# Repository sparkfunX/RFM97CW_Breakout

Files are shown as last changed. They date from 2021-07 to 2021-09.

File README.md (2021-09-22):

SparkFun RFM97C Mini Shield LoRa - 100mW
========================================

SparkFun RFM97C Mini Shield LoRa - 100mW (https://www.sparkfun.com/products/18574)

[*SparkFun RFM97C Mini Shield LoRa - 100mW (SPX-18574)*](https://www.sparkfun.com/products/18574)

The RFM97C is a great little module that incorporates the [SX1276 LoRa transceiver](https://www.semtech.com/products/wireless-rf/lora-core/sx1276) from Semtech. LoRa is best for long range communication (hundreds of feet), low power, and low data rates (~500bps). This 'Mini Shield' is designed to be attached to the top or bottom of any of our Thing Plus boards. Pictured is the [ESP32 Thing Plus](https://www.sparkfun.com/products/18018). We include a PTH soldering point for a low cost wire antenna (~3" for 915MHz) along side a stress relief hole. For folks that need a bit more oomph, there is a U.FL connector available for larger, external RP-SMA LoRa antennas.

Our example sketches make quick work of the initial setup, and the RadioLib Arduino Library makes advanced configuration and [protocols](https://github.com/jgromes/RadioLib/wiki/Default-configuration#protocols) (AX.25, Hellschreiber, Morse, RTTY, and SSTV) a cinch too!

Repository Contents
-------------------

* **/Documents** - Datasheets and mechanical drawings
* **/Firmware** - Example sketch(es)
* **/Hardware** - All Eagle design files (.brd, .sch, .STL)

Product Versions
----------------

* [SPX-18574](https://www.sparkfun.com/products/18574)

License Information
-------------------

This product is _**open source**_! 

Please review the LICENSE.md file for license information. 

If you have any questions or concerns on licensing, please contact technical support on our [SparkFun forums](https://forum.sparkfun.com/viewforum.php?f=152).

Distributed as-is; no warranty is given.

- Your friends at SparkFun.

_<COLLABORATION CREDIT>_

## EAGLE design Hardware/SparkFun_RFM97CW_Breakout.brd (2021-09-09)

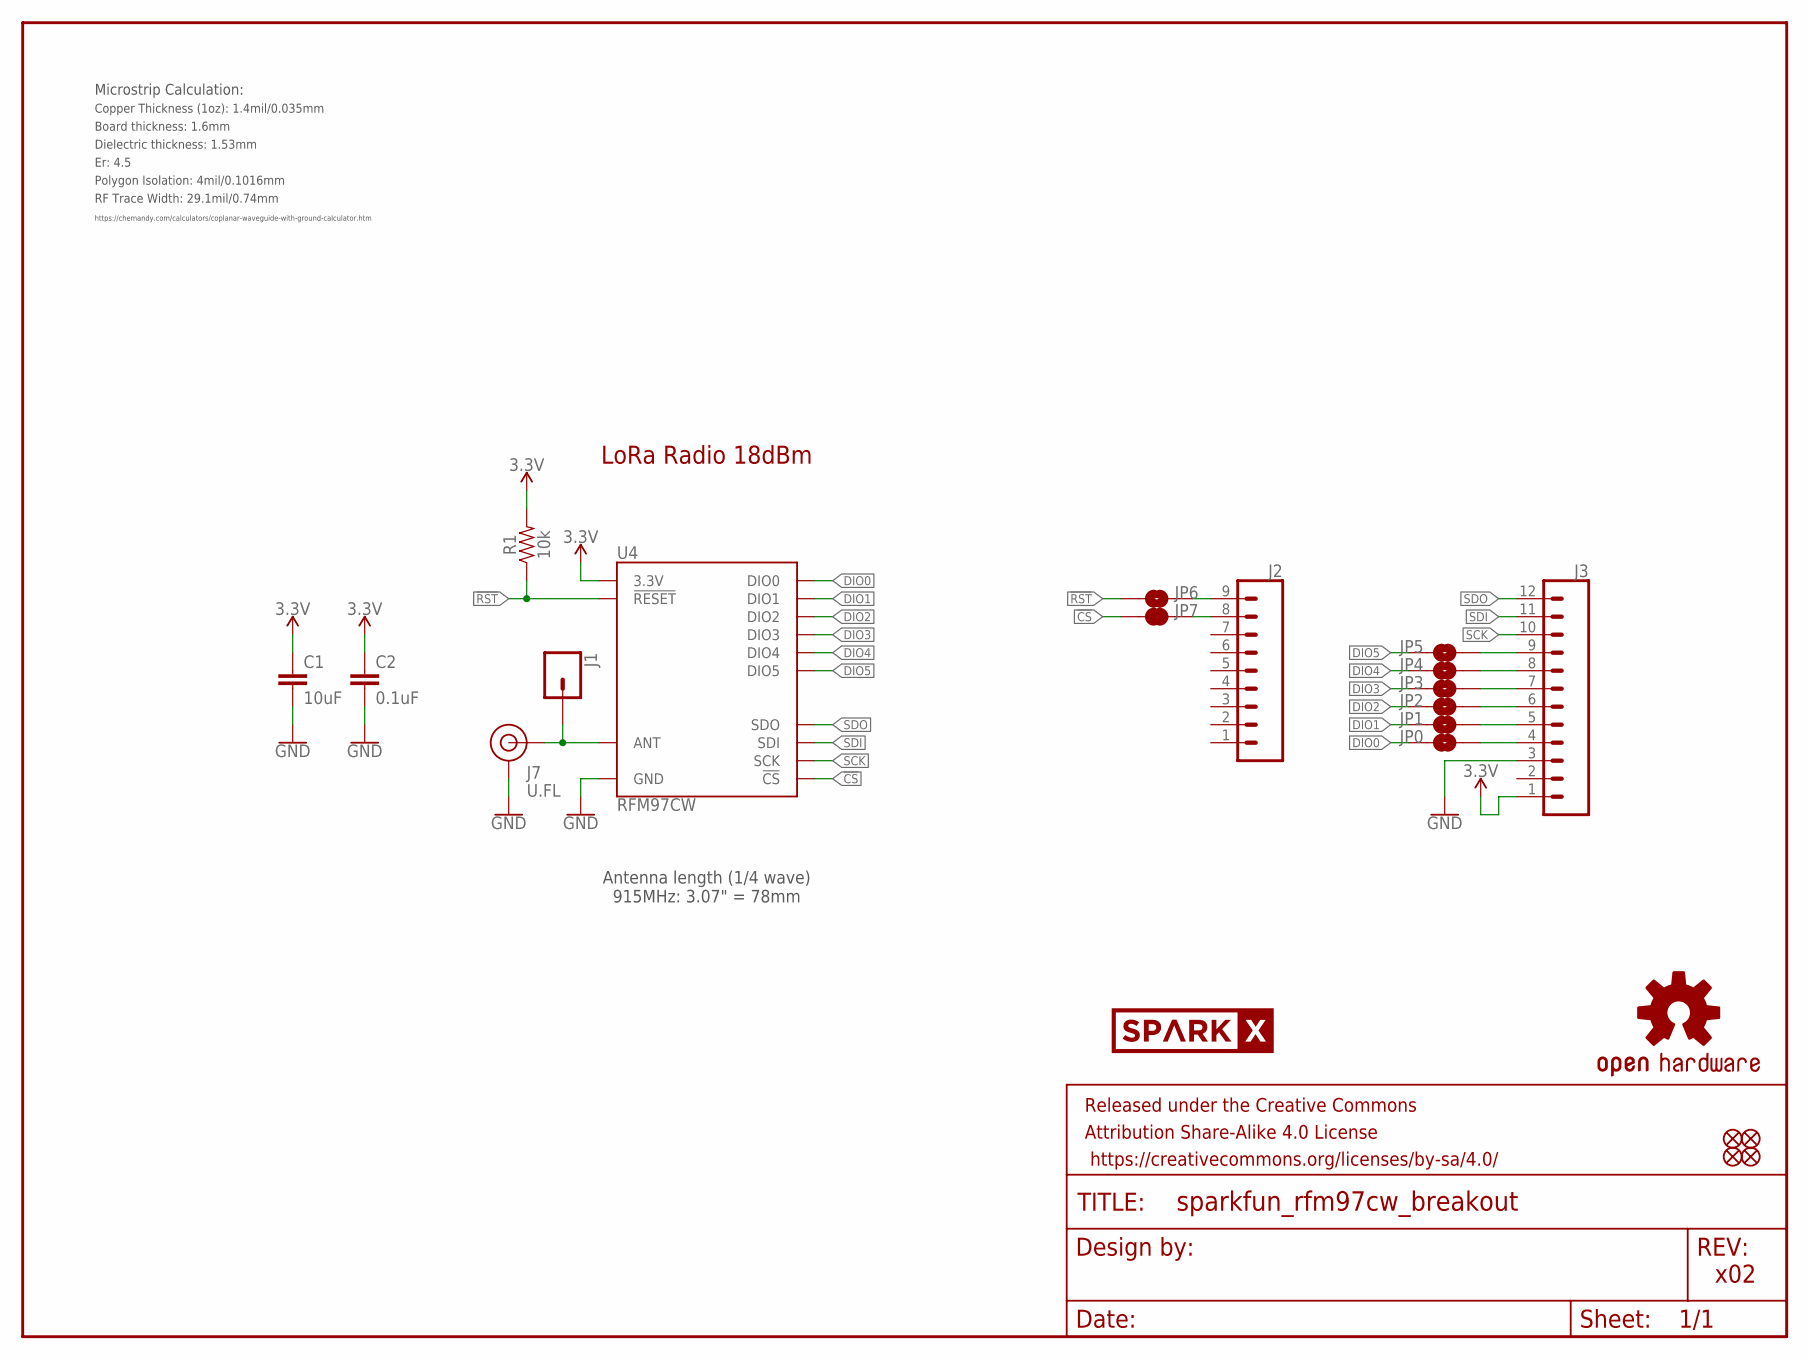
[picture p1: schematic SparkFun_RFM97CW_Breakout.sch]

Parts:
C1: 10uF; 0603
C2: 0.1uF; 0603
FID1, FID2, FID3, FID4: FIDUCIAL1X2; FIDUCIAL-1X2
FRAME1: FRAME-LETTER; CREATIVE_COMMONS
J1: CONN_01PTH_NO_SILK_YES_STOP; 1X01_NO_SILK
J2: CONN_09NO_SILK; 1X09_NO_SILK
J3: CONN_12NO_SILK; 1X12_NO_SILK
J7: U.FL
JP0, JP1, JP2, JP3, JP4, JP5, JP6: JUMPER-SMT_2_NO_NO-SILK; SMT-JUMPER_2_NO_NO-SILK
JP7: JUMPER-SMT_2_NC_TRACE_NO-SILK; SMT-JUMPER_2_NC_TRACE_NO-SILK
LOGO2: OSHW-LOGOS; OSHW-LOGO-S
R1: 10k; 0603
U4: RFM97CW; RFM97
U$22: SPARKX-LOGO5; SPARKX-LARGE

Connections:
3.3V: C1.1, C2.1, J3.1, R1.2, U4.3V3 (3.3V)
!CS!: JP7.1, U4.!CS!
!RST!: JP6.1, R1.1, U4.!RST (!RESET)
ANT: J1.1, J7.FEED (SIGNAL), U4.ANT
DIO0: JP0.1, U4.DIO0
DIO1: JP1.1, U4.DIO1
DIO2: JP2.1, U4.DIO2
DIO3: JP3.1, U4.DIO3
DIO4: JP4.1, U4.DIO4
DIO5: JP5.1, U4.DIO5
GND: C1.2, C2.2, J3.3, J7.1 (GND), J7.2 (GND), U4.GND, U4.GND@1 (GND), U4.GND@2 (GND)
unnamed: J3.6, JP2.2
unnamed: J2.9, JP6.2
unnamed: J2.8, JP7.2
unnamed: J3.5, JP1.2
unnamed: J3.4, JP0.2
unnamed: J3.7, JP3.2
unnamed: J3.8, JP4.2
unnamed: J3.9, JP5.2
SCK: J3.10, U4.SCK
SDI: J3.11, U4.SDI
SDO: J3.12, U4.SDO

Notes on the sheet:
x02
Antenna length (1/4 wave) 915MHz: 3.07" = 78mm
Board thickness: 1.6mm
Er: 4.5
Copper Thickness (1oz): 1.4mil/0.035mm
RF Trace Width: 29.1mil/0.74mm
Polygon Isolation: 4mil/0.1016mm
Dielectric thickness: 1.53mm
https://chemandy.com/calculators/coplanar-waveguide-with-ground-calculator.htm
Microstrip Calculation:
LoRa Radio 18dBm

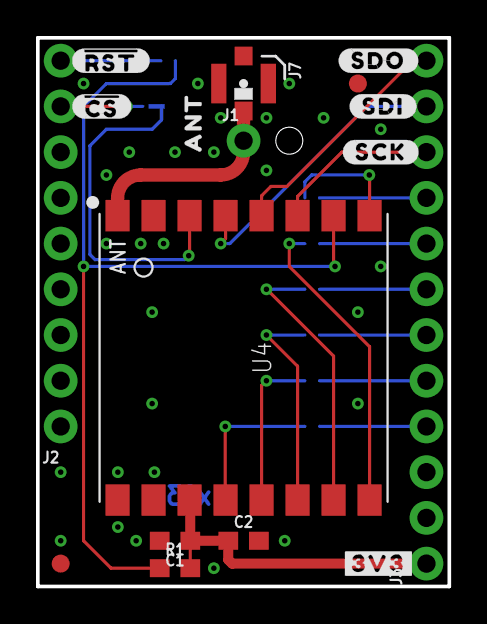
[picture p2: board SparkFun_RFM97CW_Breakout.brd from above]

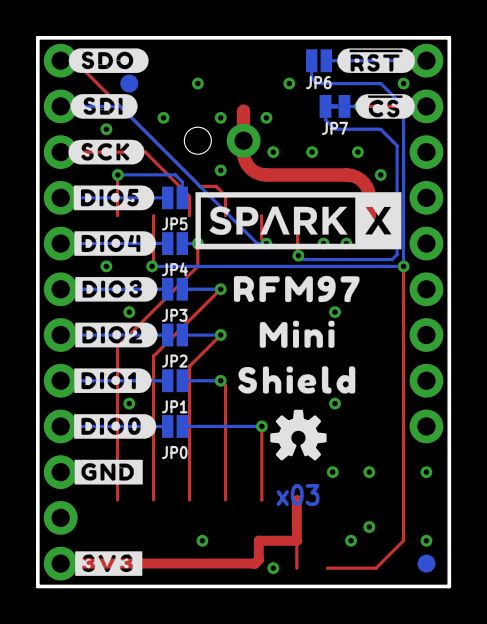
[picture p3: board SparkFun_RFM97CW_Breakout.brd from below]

Board: 2 copper layers, 22.9 x 30.5 mm, 46 parts (28 on the bottom side), 22 nets.

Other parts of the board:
U$1: ANT0
U$2, U$21: ##CS##2
U$3, U$7: #SDO#0
U$4, U$6: #SDI#1
U$5, U$12: #SCK#0
U$8, U$9: #3V3#0
U$10: #GND#1
U$11: MINI0
U$13, U$17: ##RST##0
U$19: RFM970
U$20: SHIELD2
U$23: #DIO0#0
U$24: #DIO1#0
U$25: #DIO2#0
U$26: #DIO3#0
U$27: #DIO4#0
U$28: #DIO5#0

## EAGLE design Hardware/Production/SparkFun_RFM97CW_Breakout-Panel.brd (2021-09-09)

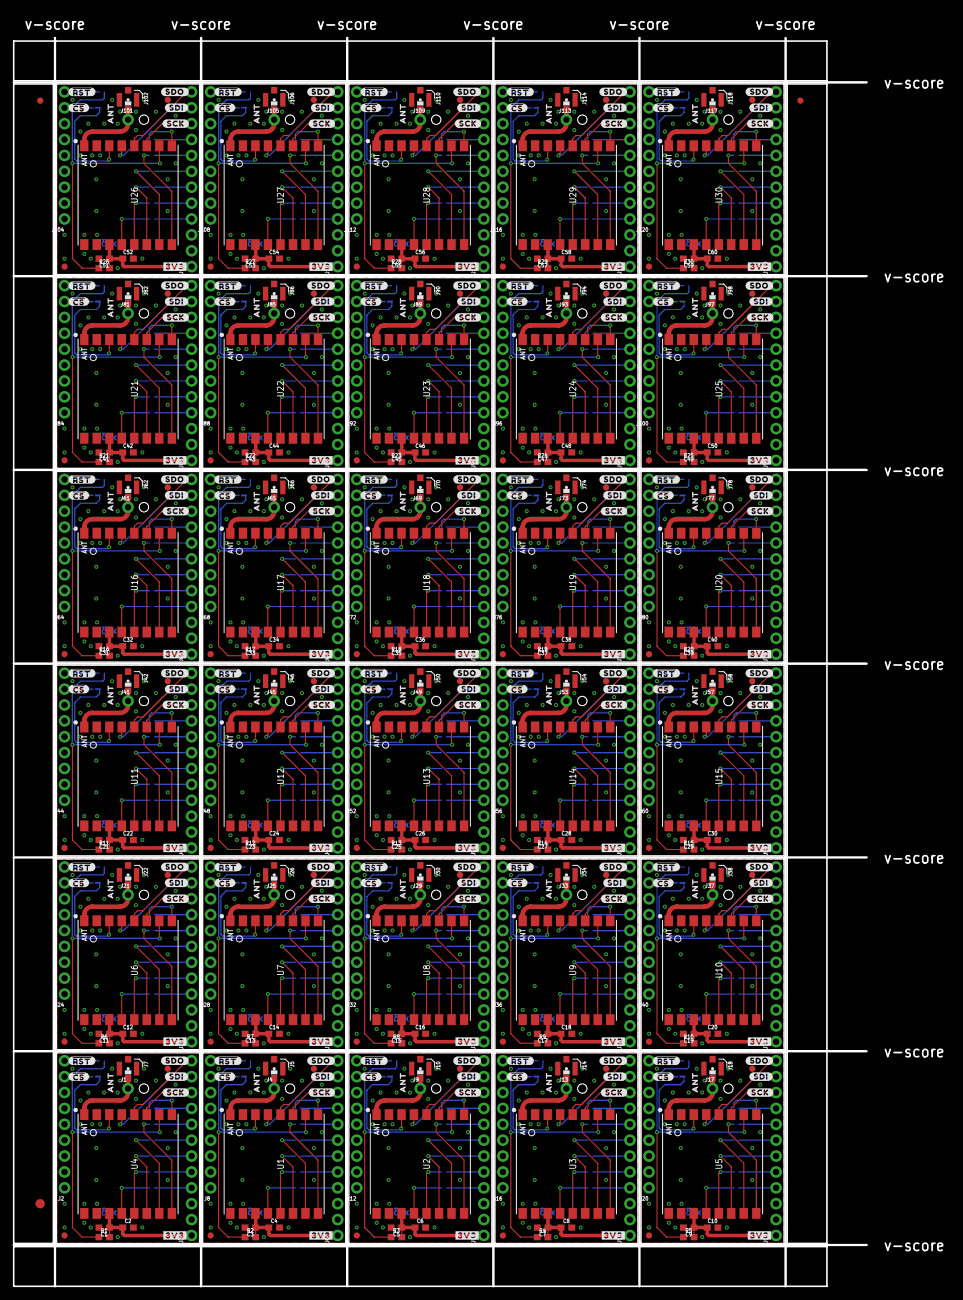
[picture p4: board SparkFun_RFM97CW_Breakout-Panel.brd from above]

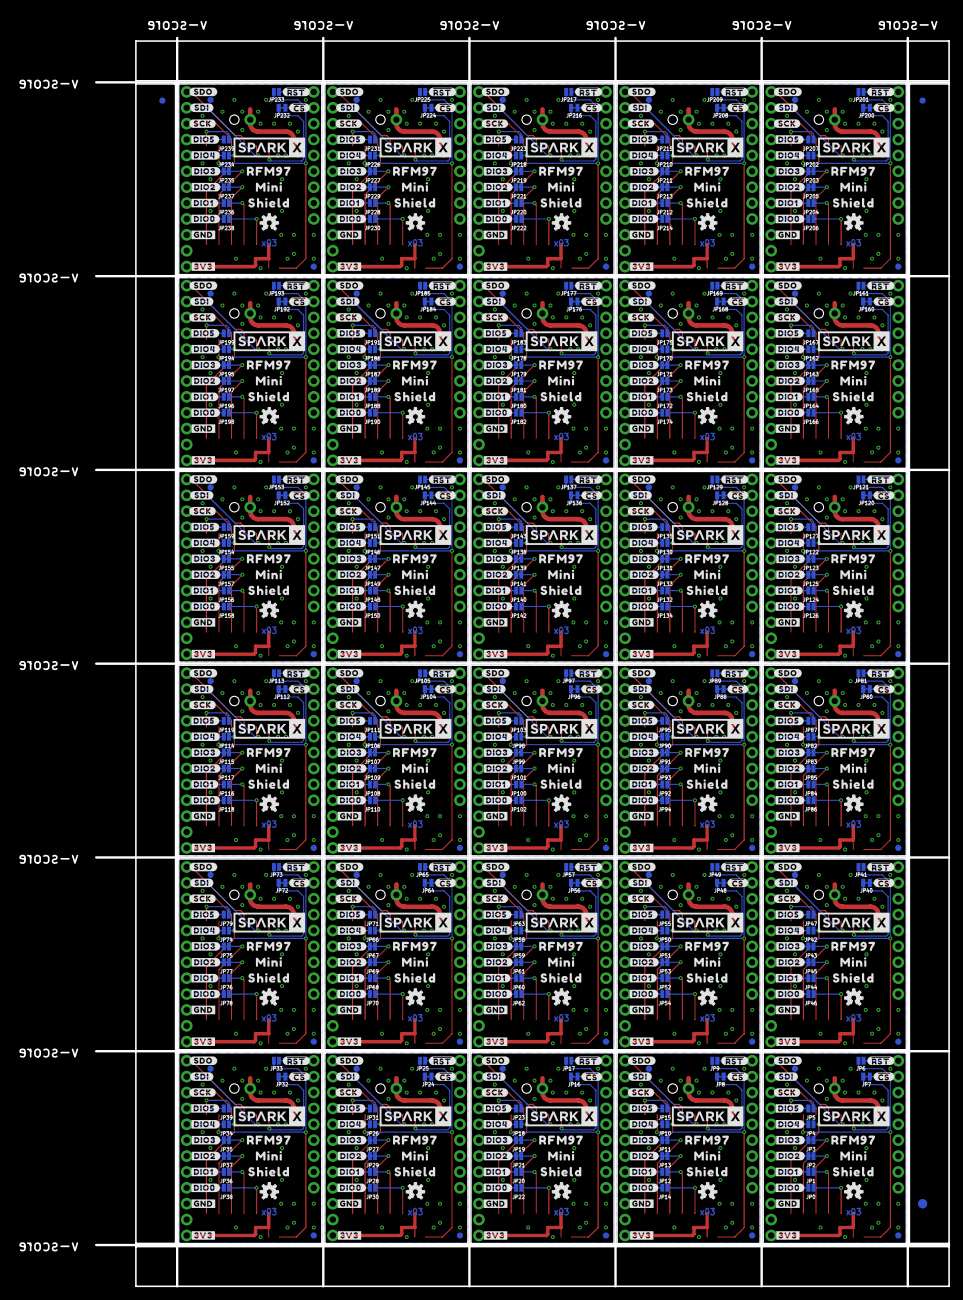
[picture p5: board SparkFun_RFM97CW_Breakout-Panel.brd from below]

Board: 2 copper layers, 136.4 x 199.6 mm, 1356 parts (843 on the bottom side), 660 nets.

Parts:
C1, C3, C5, C7, C9, C11, C13, C15, C17, C19, C21, C23, C25, C27, C29, C31, C33, C35, C37, C39, C41, C43, C45, C47, C49, C51, C53, C55, C57, C59: 10uF; 0603
C2, C4, C6, C8, C10, C12, C14, C16, C18, C20, C22, C24, C26, C28, C30, C32, C34, C36, C38, C40, C42, C44, C46, C48, C50, C52, C54, C56, C58, C60: 0.1uF; 0603
E$1, E$2, E$3, E$4: FIDUCIAL-1X2
E$5, E$6: FIDUCIAL-1.5X3
FID1, FID2, FID3, FID4, FID5, FID6, FID7, FID8, FID9, FID10, FID11, FID12, FID13, FID14, FID15, FID16, FID17, FID18, FID19, FID20, FID21, FID22, FID23, FID24, FID25, FID26, FID27, FID28, FID29, FID30, FID31, FID32, FID33, FID34, FID35, FID36, FID37, FID38, FID39, FID40, FID41, FID42, FID43, FID44, FID45, FID46, FID47, FID48, FID49, FID50, FID51, FID52, FID53, FID54, FID55, FID56, FID57, FID58, FID59, FID60, FID61, FID62, FID63, FID64, FID65, FID66, FID67, FID68, FID69, FID70, FID71, FID72, FID73, FID74, FID75, FID76, FID77, FID78, FID79, FID80, FID81, FID82, FID83, FID84, FID85, FID86, FID87, FID88, FID89, FID90, FID91, FID92, FID93, FID94, FID95, FID96, FID97, FID98, FID99, FID100, FID101, FID102, FID103, FID104, FID105, FID106, FID107, FID108, FID109, FID110, FID111, FID112, FID113, FID114, FID115, FID116, FID117, FID118, FID119, FID120: FIDUCIAL1X2; FIDUCIAL-1X2
J1, J4, J9, J13, J17, J21, J25, J29, J33, J37, J41, J45, J49, J53, J57, J61, J65, J69, J73, J77, J81, J85, J89, J93, J97, J101, J105, J109, J113, J117: 1X01_NO_SILK
J2, J8, J12, J16, J20, J24, J28, J32, J36, J40, J44, J48, J52, J56, J60, J64, J68, J72, J76, J80, J84, J88, J92, J96, J100, J104, J108, J112, J116, J120: 1X09_NO_SILK
J3, J6, J11, J15, J19, J23, J27, J31, J35, J39, J43, J47, J51, J55, J59, J63, J67, J71, J75, J79, J83, J87, J91, J95, J99, J103, J107, J111, J115, J119: 1X12_NO_SILK
J5, J7, J10, J14, J18, J22, J26, J30, J34, J38, J42, J46, J50, J54, J58, J62, J66, J70, J74, J78, J82, J86, J90, J94, J98, J102, J106, J110, J114, J118: U.FL
JP0, JP1, JP2, JP3, JP4, JP5, JP6, JP9, JP10, JP11, JP12, JP13, JP14, JP15, JP17, JP18, JP19, JP20, JP21, JP22, JP23, JP25, JP26, JP27, JP28, JP29, JP30, JP31, JP33, JP34, JP35, JP36, JP37, JP38, JP39, JP41, JP42, JP43, JP44, JP45, JP46, JP47, JP49, JP50, JP51, JP52, JP53, JP54, JP55, JP57, JP58, JP59, JP60, JP61, JP62, JP63, JP65, JP66, JP67, JP68, JP69, JP70, JP71, JP73, JP74, JP75, JP76, JP77, JP78, JP79, JP81, JP82, JP83, JP84, JP85, JP86, JP87, JP89, JP90, JP91, JP92, JP93, JP94, JP95, JP97, JP98, JP99, JP100, JP101, JP102, JP103, JP105, JP106, JP107, JP108, JP109, JP110, JP111, JP113, JP114, JP115, JP116, JP117, JP118, JP119, JP121, JP122, JP123, JP124, JP125, JP126, JP127, JP129, JP130, JP131, JP132, JP133, JP134, JP135, JP137, JP138, JP139, JP140, JP141, JP142, JP143, JP145, JP146, JP147, JP148, JP149, JP150, JP151, JP153, JP154, JP155, JP156, JP157, JP158, JP159, JP161, JP162, JP163, JP164, JP165, JP166, JP167, JP169, JP170, JP171, JP172, JP173, JP174, JP175, JP177, JP178, JP179, JP180, JP181, JP182, JP183, JP185, JP186, JP187, JP188, JP189, JP190, JP191, JP193, JP194, JP195, JP196, JP197, JP198, JP199, JP201, JP202, JP203, JP204, JP205, JP206, JP207, JP209, JP210, JP211, JP212, JP213, JP214, JP215, JP217, JP218, JP219, JP220, JP221, JP222, JP223, JP225, JP226, JP227, JP228, JP229, JP230, JP231, JP233, JP234, JP235, JP236, JP237, JP238, JP239: JUMPER-SMT_2_NO_NO-SILK; SMT-JUMPER_2_NO_NO-SILK
JP7, JP8, JP16, JP24, JP32, JP40, JP48, JP56, JP64, JP72, JP80, JP88, JP96, JP104, JP112, JP120, JP128, JP136, JP144, JP152, JP160, JP168, JP176, JP184, JP192, JP200, JP208, JP216, JP224, JP232: JUMPER-SMT_2_NC_TRACE_NO-SILK; SMT-JUMPER_2_NC_TRACE_NO-SILK
LOGO1, LOGO2, LOGO3, LOGO4, LOGO5, LOGO6, LOGO7, LOGO8, LOGO9, LOGO10, LOGO11, LOGO12, LOGO13, LOGO14, LOGO15, LOGO16, LOGO17, LOGO18, LOGO19, LOGO20, LOGO21, LOGO22, LOGO23, LOGO24, LOGO25, LOGO26, LOGO27, LOGO28, LOGO29, LOGO30: OSHW-LOGOS; OSHW-LOGO-S
R1, R2, R3, R4, R5, R6, R7, R8, R9, R10, R11, R12, R13, R14, R15, R16, R17, R18, R19, R20, R21, R22, R23, R24, R25, R26, R27, R28, R29, R30: 10k; 0603
U1, U2, U3, U4, U5, U6, U7, U8, U9, U10, U11, U12, U13, U14, U15, U16, U17, U18, U19, U20, U21, U22, U23, U24, U25, U26, U27, U28, U29, U30: RFM97CW; RFM97
U$1, U$14, U$49, U$73, U$97, U$121, U$145, U$169, U$193, U$217, U$241, U$265, U$289, U$313, U$337, U$361, U$385, U$409, U$433, U$457, U$481, U$505, U$529, U$553, U$577, U$601, U$625, U$649, U$673, U$697: ANT0
U$2, U$21, U$33, U$34, U$57, U$58, U$81, U$82, U$105, U$106, U$129, U$130, U$153, U$154, U$177, U$178, U$201, U$202, U$225, U$226, U$249, U$250, U$273, U$274, U$297, U$298, U$321, U$322, U$345, U$346, U$369, U$370, U$393, U$394, U$417, U$418, U$441, U$442, U$465, U$466, U$489, U$490, U$513, U$514, U$537, U$538, U$561, U$562, U$585, U$586, U$609, U$610, U$633, U$634, U$657, U$658, U$681, U$682, U$705, U$706: ##CS##2
U$3, U$7, U$16, U$35, U$51, U$59, U$75, U$83, U$99, U$107, U$123, U$131, U$147, U$155, U$171, U$179, U$195, U$203, U$219, U$227, U$243, U$251, U$267, U$275, U$291, U$299, U$315, U$323, U$339, U$347, U$363, U$371, U$387, U$395, U$411, U$419, U$435, U$443, U$459, U$467, U$483, U$491, U$507, U$515, U$531, U$539, U$555, U$563, U$579, U$587, U$603, U$611, U$627, U$635, U$651, U$659, U$675, U$683, U$699, U$707: #SDO#0
U$4, U$6, U$15, U$36, U$50, U$60, U$74, U$84, U$98, U$108, U$122, U$132, U$146, U$156, U$170, U$180, U$194, U$204, U$218, U$228, U$242, U$252, U$266, U$276, U$290, U$300, U$314, U$324, U$338, U$348, U$362, U$372, U$386, U$396, U$410, U$420, U$434, U$444, U$458, U$468, U$482, U$492, U$506, U$516, U$530, U$540, U$554, U$564, U$578, U$588, U$602, U$612, U$626, U$636, U$650, U$660, U$674, U$684, U$698, U$708: #SDI#1
U$5, U$12, U$45, U$46, U$69, U$70, U$93, U$94, U$117, U$118, U$141, U$142, U$165, U$166, U$189, U$190, U$213, U$214, U$237, U$238, U$261, U$262, U$285, U$286, U$309, U$310, U$333, U$334, U$357, U$358, U$381, U$382, U$405, U$406, U$429, U$430, U$453, U$454, U$477, U$478, U$501, U$502, U$525, U$526, U$549, U$550, U$573, U$574, U$597, U$598, U$621, U$622, U$645, U$646, U$669, U$670, U$693, U$694, U$717, U$718: #SCK#0
U$8, U$9, U$18, U$29, U$52, U$53, U$76, U$77, U$100, U$101, U$124, U$125, U$148, U$149, U$172, U$173, U$196, U$197, U$220, U$221, U$244, U$245, U$268, U$269, U$292, U$293, U$316, U$317, U$340, U$341, U$364, U$365, U$388, U$389, U$412, U$413, U$436, U$437, U$460, U$461, U$484, U$485, U$508, U$509, U$532, U$533, U$556, U$557, U$580, U$581, U$604, U$605, U$628, U$629, U$652, U$653, U$676, U$677, U$700, U$701: #3V3#0
U$10, U$30, U$54, U$78, U$102, U$126, U$150, U$174, U$198, U$222, U$246, U$270, U$294, U$318, U$342, U$366, U$390, U$414, U$438, U$462, U$486, U$510, U$534, U$558, U$582, U$606, U$630, U$654, U$678, U$702: #GND#1
U$11, U$48, U$72, U$96, U$120, U$144, U$168, U$192, U$216, U$240, U$264, U$288, U$312, U$336, U$360, U$384, U$408, U$432, U$456, U$480, U$504, U$528, U$552, U$576, U$600, U$624, U$648, U$672, U$696, U$720: MINI0
U$13, U$17, U$38, U$47, U$62, U$71, U$86, U$95, U$110, U$119, U$134, U$143, U$158, U$167, U$182, U$191, U$206, U$215, U$230, U$239, U$254, U$263, U$278, U$287, U$302, U$311, U$326, U$335, U$350, U$359, U$374, U$383, U$398, U$407, U$422, U$431, U$446, U$455, U$470, U$479, U$494, U$503, U$518, U$527, U$542, U$551, U$566, U$575, U$590, U$599, U$614, U$623, U$638, U$647, U$662, U$671, U$686, U$695, U$710, U$719: ##RST##0
U$19, U$31, U$55, U$79, U$103, U$127, U$151, U$175, U$199, U$223, U$247, U$271, U$295, U$319, U$343, U$367, U$391, U$415, U$439, U$463, U$487, U$511, U$535, U$559, U$583, U$607, U$631, U$655, U$679, U$703: RFM970
U$20, U$32, U$56, U$80, U$104, U$128, U$152, U$176, U$200, U$224, U$248, U$272, U$296, U$320, U$344, U$368, U$392, U$416, U$440, U$464, U$488, U$512, U$536, U$560, U$584, U$608, U$632, U$656, U$680, U$704: SHIELD2
U$22, U$37, U$61, U$85, U$109, U$133, U$157, U$181, U$205, U$229, U$253, U$277, U$301, U$325, U$349, U$373, U$397, U$421, U$445, U$469, U$493, U$517, U$541, U$565, U$589, U$613, U$637, U$661, U$685, U$709: SPARKX-LOGO5; SPARKX-LARGE
U$23, U$39, U$63, U$87, U$111, U$135, U$159, U$183, U$207, U$231, U$255, U$279, U$303, U$327, U$351, U$375, U$399, U$423, U$447, U$471, U$495, U$519, U$543, U$567, U$591, U$615, U$639, U$663, U$687, U$711: #DIO0#0
U$24, U$40, U$64, U$88, U$112, U$136, U$160, U$184, U$208, U$232, U$256, U$280, U$304, U$328, U$352, U$376, U$400, U$424, U$448, U$472, U$496, U$520, U$544, U$568, U$592, U$616, U$640, U$664, U$688, U$712: #DIO1#0
U$25, U$41, U$65, U$89, U$113, U$137, U$161, U$185, U$209, U$233, U$257, U$281, U$305, U$329, U$353, U$377, U$401, U$425, U$449, U$473, U$497, U$521, U$545, U$569, U$593, U$617, U$641, U$665, U$689, U$713: #DIO2#0
U$26, U$42, U$66, U$90, U$114, U$138, U$162, U$186, U$210, U$234, U$258, U$282, U$306, U$330, U$354, U$378, U$402, U$426, U$450, U$474, U$498, U$522, U$546, U$570, U$594, U$618, U$642, U$666, U$690, U$714: #DIO3#0
U$27, U$43, U$67, U$91, U$115, U$139, U$163, U$187, U$211, U$235, U$259, U$283, U$307, U$331, U$355, U$379, U$403, U$427, U$451, U$475, U$499, U$523, U$547, U$571, U$595, U$619, U$643, U$667, U$691, U$715: #DIO4#0
U$28, U$44, U$68, U$92, U$116, U$140, U$164, U$188, U$212, U$236, U$260, U$284, U$308, U$332, U$356, U$380, U$404, U$428, U$452, U$476, U$500, U$524, U$548, U$572, U$596, U$620, U$644, U$668, U$692, U$716: #DIO5#0

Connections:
3.3V: C1.1, C2.1, J3.1, R1.2, U4.3V3
3.3V1: C3.1, C4.1, J6.1, R2.2, U1.3V3
3.3V2: C5.1, C6.1, J11.1, R3.2, U2.3V3
3.3V3: C7.1, C8.1, J15.1, R4.2, U3.3V3
3.3V4: C9.1, C10.1, J19.1, R5.2, U5.3V3
3.3V5: C11.1, C12.1, J23.1, R6.2, U6.3V3
3.3V6: C13.1, C14.1, J27.1, R7.2, U7.3V3
3.3V7: C15.1, C16.1, J31.1, R8.2, U8.3V3
3.3V8: C17.1, C18.1, J35.1, R9.2, U9.3V3
3.3V9: C19.1, C20.1, J39.1, R10.2, U10.3V3
3.3V10: C21.1, C22.1, J43.1, R11.2, U11.3V3
3.3V11: C23.1, C24.1, J47.1, R12.2, U12.3V3
3.3V12: C25.1, C26.1, J51.1, R13.2, U13.3V3
3.3V13: C27.1, C28.1, J55.1, R14.2, U14.3V3
3.3V14: C29.1, C30.1, J59.1, R15.2, U15.3V3
3.3V15: C31.1, C32.1, J63.1, R16.2, U16.3V3
3.3V16: C33.1, C34.1, J67.1, R17.2, U17.3V3
3.3V17: C35.1, C36.1, J71.1, R18.2, U18.3V3
3.3V18: C37.1, C38.1, J75.1, R19.2, U19.3V3
3.3V19: C39.1, C40.1, J79.1, R20.2, U20.3V3
3.3V20: C41.1, C42.1, J83.1, R21.2, U21.3V3
3.3V21: C43.1, C44.1, J87.1, R22.2, U22.3V3
3.3V22: C45.1, C46.1, J91.1, R23.2, U23.3V3
3.3V23: C47.1, C48.1, J95.1, R24.2, U24.3V3
3.3V24: C49.1, C50.1, J99.1, R25.2, U25.3V3
3.3V25: C51.1, C52.1, J103.1, R26.2, U26.3V3
3.3V26: C53.1, C54.1, J107.1, R27.2, U27.3V3
3.3V27: C55.1, C56.1, J111.1, R28.2, U28.3V3
3.3V28: C57.1, C58.1, J115.1, R29.2, U29.3V3
3.3V29: C59.1, C60.1, J119.1, R30.2, U30.3V3
!CS!: JP7.1, U4.!CS!
!CS!1: JP8.1, U1.!CS!
!CS!2: JP16.1, U2.!CS!
!CS!3: JP24.1, U3.!CS!
!CS!4: JP32.1, U5.!CS!
!CS!5: JP40.1, U6.!CS!
!CS!6: JP48.1, U7.!CS!
!CS!7: JP56.1, U8.!CS!
!CS!8: JP64.1, U9.!CS!
!CS!9: JP72.1, U10.!CS!
!CS!10: JP80.1, U11.!CS!
!CS!11: JP88.1, U12.!CS!
!CS!12: JP96.1, U13.!CS!
!CS!13: JP104.1, U14.!CS!
!CS!14: JP112.1, U15.!CS!
!CS!15: JP120.1, U16.!CS!
!CS!16: JP128.1, U17.!CS!
!CS!17: JP136.1, U18.!CS!
!CS!18: JP144.1, U19.!CS!
!CS!19: JP152.1, U20.!CS!
!CS!20: JP160.1, U21.!CS!
!CS!21: JP168.1, U22.!CS!
!CS!22: JP176.1, U23.!CS!
!CS!23: JP184.1, U24.!CS!
!CS!24: JP192.1, U25.!CS!
!CS!25: JP200.1, U26.!CS!
!CS!26: JP208.1, U27.!CS!
!CS!27: JP216.1, U28.!CS!
!CS!28: JP224.1, U29.!CS!
!CS!29: JP232.1, U30.!CS!
!RST!: JP6.1, R1.1, U4.!RST
!RST!1: JP9.1, R2.1, U1.!RST
!RST!2: JP17.1, R3.1, U2.!RST
!RST!3: JP25.1, R4.1, U3.!RST
!RST!4: JP33.1, R5.1, U5.!RST
!RST!5: JP41.1, R6.1, U6.!RST
!RST!6: JP49.1, R7.1, U7.!RST
!RST!7: JP57.1, R8.1, U8.!RST
!RST!8: JP65.1, R9.1, U9.!RST
!RST!9: JP73.1, R10.1, U10.!RST
!RST!10: JP81.1, R11.1, U11.!RST
!RST!11: JP89.1, R12.1, U12.!RST
!RST!12: JP97.1, R13.1, U13.!RST
!RST!13: JP105.1, R14.1, U14.!RST
!RST!14: JP113.1, R15.1, U15.!RST
!RST!15: JP121.1, R16.1, U16.!RST
!RST!16: JP129.1, R17.1, U17.!RST
!RST!17: JP137.1, R18.1, U18.!RST
!RST!18: JP145.1, R19.1, U19.!RST
!RST!19: JP153.1, R20.1, U20.!RST
!RST!20: JP161.1, R21.1, U21.!RST
!RST!21: JP169.1, R22.1, U22.!RST
!RST!22: JP177.1, R23.1, U23.!RST
!RST!23: JP185.1, R24.1, U24.!RST
!RST!24: JP193.1, R25.1, U25.!RST
!RST!25: JP201.1, R26.1, U26.!RST
!RST!26: JP209.1, R27.1, U27.!RST
!RST!27: JP217.1, R28.1, U28.!RST
!RST!28: JP225.1, R29.1, U29.!RST
!RST!29: JP233.1, R30.1, U30.!RST
ANT: J1.1, J7.FEED, U4.ANT
ANT1: J4.1, J5.FEED, U1.ANT
ANT2: J9.1, J10.FEED, U2.ANT
ANT3: J13.1, J14.FEED, U3.ANT
ANT4: J17.1, J18.FEED, U5.ANT
ANT5: J21.1, J22.FEED, U6.ANT
ANT6: J25.1, J26.FEED, U7.ANT
ANT7: J29.1, J30.FEED, U8.ANT
ANT8: J33.1, J34.FEED, U9.ANT
ANT9: J37.1, J38.FEED, U10.ANT
ANT10: J41.1, J42.FEED, U11.ANT
ANT11: J45.1, J46.FEED, U12.ANT
ANT12: J49.1, J50.FEED, U13.ANT
ANT13: J53.1, J54.FEED, U14.ANT
ANT14: J57.1, J58.FEED, U15.ANT
ANT15: J61.1, J62.FEED, U16.ANT
ANT16: J65.1, J66.FEED, U17.ANT
ANT17: J69.1, J70.FEED, U18.ANT
ANT18: J73.1, J74.FEED, U19.ANT
ANT19: J77.1, J78.FEED, U20.ANT
ANT20: J81.1, J82.FEED, U21.ANT
ANT21: J85.1, J86.FEED, U22.ANT
ANT22: J89.1, J90.FEED, U23.ANT
ANT23: J93.1, J94.FEED, U24.ANT
ANT24: J97.1, J98.FEED, U25.ANT
ANT25: J101.1, J102.FEED, U26.ANT
ANT26: J105.1, J106.FEED, U27.ANT
ANT27: J109.1, J110.FEED, U28.ANT
ANT28: J113.1, J114.FEED, U29.ANT
ANT29: J117.1, J118.FEED, U30.ANT
DIO0: JP0.1, U4.DIO0
DIO1: JP1.1, U4.DIO1
DIO2: JP2.1, U4.DIO2
DIO3: JP3.1, U4.DIO3
DIO4: JP4.1, U4.DIO4
DIO5: JP5.1, U4.DIO5
DIO6: JP14.1, U1.DIO0
DIO7: JP12.1, U1.DIO1
DIO8: JP13.1, U1.DIO2
DIO9: JP11.1, U1.DIO3
DIO10: JP10.1, U1.DIO4
DIO11: JP15.1, U1.DIO5
DIO12: JP22.1, U2.DIO0
DIO13: JP20.1, U2.DIO1
DIO14: JP21.1, U2.DIO2
DIO15: JP19.1, U2.DIO3
DIO16: JP18.1, U2.DIO4
DIO17: JP23.1, U2.DIO5
DIO18: JP30.1, U3.DIO0
DIO19: JP28.1, U3.DIO1
DIO20: JP29.1, U3.DIO2
DIO21: JP27.1, U3.DIO3
DIO22: JP26.1, U3.DIO4
DIO23: JP31.1, U3.DIO5
DIO24: JP38.1, U5.DIO0
DIO25: JP36.1, U5.DIO1
DIO26: JP37.1, U5.DIO2
DIO27: JP35.1, U5.DIO3
DIO28: JP34.1, U5.DIO4
DIO29: JP39.1, U5.DIO5
DIO30: JP46.1, U6.DIO0
DIO31: JP44.1, U6.DIO1
DIO32: JP45.1, U6.DIO2
DIO33: JP43.1, U6.DIO3
DIO34: JP42.1, U6.DIO4
DIO35: JP47.1, U6.DIO5
DIO36: JP54.1, U7.DIO0
DIO37: JP52.1, U7.DIO1
DIO38: JP53.1, U7.DIO2
DIO39: JP51.1, U7.DIO3
DIO40: JP50.1, U7.DIO4
DIO41: JP55.1, U7.DIO5
DIO42: JP62.1, U8.DIO0
DIO43: JP60.1, U8.DIO1
DIO44: JP61.1, U8.DIO2
DIO45: JP59.1, U8.DIO3
DIO46: JP58.1, U8.DIO4
DIO47: JP63.1, U8.DIO5
DIO48: JP70.1, U9.DIO0
DIO49: JP68.1, U9.DIO1
DIO50: JP69.1, U9.DIO2
DIO51: JP67.1, U9.DIO3
DIO52: JP66.1, U9.DIO4
DIO53: JP71.1, U9.DIO5
DIO54: JP78.1, U10.DIO0
DIO55: JP76.1, U10.DIO1
DIO56: JP77.1, U10.DIO2
DIO57: JP75.1, U10.DIO3
DIO58: JP74.1, U10.DIO4
DIO59: JP79.1, U10.DIO5
DIO60: JP86.1, U11.DIO0
DIO61: JP84.1, U11.DIO1
DIO62: JP85.1, U11.DIO2
DIO63: JP83.1, U11.DIO3
DIO64: JP82.1, U11.DIO4
DIO65: JP87.1, U11.DIO5
DIO66: JP94.1, U12.DIO0
DIO67: JP92.1, U12.DIO1
DIO68: JP93.1, U12.DIO2
DIO69: JP91.1, U12.DIO3
DIO70: JP90.1, U12.DIO4
DIO71: JP95.1, U12.DIO5
DIO72: JP102.1, U13.DIO0
DIO73: JP100.1, U13.DIO1
DIO74: JP101.1, U13.DIO2
DIO75: JP99.1, U13.DIO3
DIO76: JP98.1, U13.DIO4
DIO77: JP103.1, U13.DIO5
DIO78: JP110.1, U14.DIO0
DIO79: JP108.1, U14.DIO1
DIO80: JP109.1, U14.DIO2
DIO81: JP107.1, U14.DIO3
DIO82: JP106.1, U14.DIO4
DIO83: JP111.1, U14.DIO5
DIO84: JP118.1, U15.DIO0
DIO85: JP116.1, U15.DIO1
DIO86: JP117.1, U15.DIO2
DIO87: JP115.1, U15.DIO3
DIO88: JP114.1, U15.DIO4
DIO89: JP119.1, U15.DIO5
DIO90: JP126.1, U16.DIO0
DIO91: JP124.1, U16.DIO1
DIO92: JP125.1, U16.DIO2
DIO93: JP123.1, U16.DIO3
DIO94: JP122.1, U16.DIO4
DIO95: JP127.1, U16.DIO5
DIO96: JP134.1, U17.DIO0
DIO97: JP132.1, U17.DIO1
DIO98: JP133.1, U17.DIO2
DIO99: JP131.1, U17.DIO3
DIO100: JP130.1, U17.DIO4
DIO101: JP135.1, U17.DIO5
DIO102: JP142.1, U18.DIO0
DIO103: JP140.1, U18.DIO1
DIO104: JP141.1, U18.DIO2
DIO105: JP139.1, U18.DIO3
DIO106: JP138.1, U18.DIO4
DIO107: JP143.1, U18.DIO5
DIO108: JP150.1, U19.DIO0
DIO109: JP148.1, U19.DIO1
DIO110: JP149.1, U19.DIO2
DIO111: JP147.1, U19.DIO3
DIO112: JP146.1, U19.DIO4
DIO113: JP151.1, U19.DIO5
DIO114: JP158.1, U20.DIO0
DIO115: JP156.1, U20.DIO1
DIO116: JP157.1, U20.DIO2
DIO117: JP155.1, U20.DIO3
DIO118: JP154.1, U20.DIO4
DIO119: JP159.1, U20.DIO5
DIO120: JP166.1, U21.DIO0
DIO121: JP164.1, U21.DIO1
DIO122: JP165.1, U21.DIO2
DIO123: JP163.1, U21.DIO3
DIO124: JP162.1, U21.DIO4
DIO125: JP167.1, U21.DIO5
DIO126: JP174.1, U22.DIO0
DIO127: JP172.1, U22.DIO1
DIO128: JP173.1, U22.DIO2
DIO129: JP171.1, U22.DIO3
DIO130: JP170.1, U22.DIO4
DIO131: JP175.1, U22.DIO5
DIO132: JP182.1, U23.DIO0
DIO133: JP180.1, U23.DIO1
DIO134: JP181.1, U23.DIO2
DIO135: JP179.1, U23.DIO3
DIO136: JP178.1, U23.DIO4
DIO137: JP183.1, U23.DIO5
DIO138: JP190.1, U24.DIO0
DIO139: JP188.1, U24.DIO1
DIO140: JP189.1, U24.DIO2
DIO141: JP187.1, U24.DIO3
DIO142: JP186.1, U24.DIO4
DIO143: JP191.1, U24.DIO5
DIO144: JP198.1, U25.DIO0
DIO145: JP196.1, U25.DIO1
DIO146: JP197.1, U25.DIO2
DIO147: JP195.1, U25.DIO3
DIO148: JP194.1, U25.DIO4
DIO149: JP199.1, U25.DIO5
DIO150: JP206.1, U26.DIO0
DIO151: JP204.1, U26.DIO1
DIO152: JP205.1, U26.DIO2
DIO153: JP203.1, U26.DIO3
DIO154: JP202.1, U26.DIO4
DIO155: JP207.1, U26.DIO5
DIO156: JP214.1, U27.DIO0
DIO157: JP212.1, U27.DIO1
DIO158: JP213.1, U27.DIO2
DIO159: JP211.1, U27.DIO3
DIO160: JP210.1, U27.DIO4
DIO161: JP215.1, U27.DIO5
DIO162: JP222.1, U28.DIO0
DIO163: JP220.1, U28.DIO1
DIO164: JP221.1, U28.DIO2
DIO165: JP219.1, U28.DIO3
DIO166: JP218.1, U28.DIO4
DIO167: JP223.1, U28.DIO5
DIO168: JP230.1, U29.DIO0
DIO169: JP228.1, U29.DIO1
DIO170: JP229.1, U29.DIO2
DIO171: JP227.1, U29.DIO3
DIO172: JP226.1, U29.DIO4
DIO173: JP231.1, U29.DIO5
DIO174: JP238.1, U30.DIO0
DIO175: JP236.1, U30.DIO1
DIO176: JP237.1, U30.DIO2
DIO177: JP235.1, U30.DIO3
DIO178: JP234.1, U30.DIO4
DIO179: JP239.1, U30.DIO5
GND: C1.2, C2.2, J3.3, J7.1, J7.2, U4.GND, U4.GND@1, U4.GND@2
GND1: C3.2, C4.2, J5.1, J5.2, J6.3, U1.GND, U1.GND@1, U1.GND@2
GND2: C5.2, C6.2, J10.1, J10.2, J11.3, U2.GND, U2.GND@1, U2.GND@2
GND3: C7.2, C8.2, J14.1, J14.2, J15.3, U3.GND, U3.GND@1, U3.GND@2
GND4: C9.2, C10.2, J18.1, J18.2, J19.3, U5.GND, U5.GND@1, U5.GND@2
GND5: C11.2, C12.2, J22.1, J22.2, J23.3, U6.GND, U6.GND@1, U6.GND@2
GND6: C13.2, C14.2, J26.1, J26.2, J27.3, U7.GND, U7.GND@1, U7.GND@2
GND7: C15.2, C16.2, J30.1, J30.2, J31.3, U8.GND, U8.GND@1, U8.GND@2
GND8: C17.2, C18.2, J34.1, J34.2, J35.3, U9.GND, U9.GND@1, U9.GND@2
GND9: C19.2, C20.2, J38.1, J38.2, J39.3, U10.GND, U10.GND@1, U10.GND@2
GND10: C21.2, C22.2, J42.1, J42.2, J43.3, U11.GND, U11.GND@1, U11.GND@2
GND11: C23.2, C24.2, J46.1, J46.2, J47.3, U12.GND, U12.GND@1, U12.GND@2
GND12: C25.2, C26.2, J50.1, J50.2, J51.3, U13.GND, U13.GND@1, U13.GND@2
GND13: C27.2, C28.2, J54.1, J54.2, J55.3, U14.GND, U14.GND@1, U14.GND@2
GND14: C29.2, C30.2, J58.1, J58.2, J59.3, U15.GND, U15.GND@1, U15.GND@2
GND15: C31.2, C32.2, J62.1, J62.2, J63.3, U16.GND, U16.GND@1, U16.GND@2
GND16: C33.2, C34.2, J66.1, J66.2, J67.3, U17.GND, U17.GND@1, U17.GND@2
GND17: C35.2, C36.2, J70.1, J70.2, J71.3, U18.GND, U18.GND@1, U18.GND@2
GND18: C37.2, C38.2, J74.1, J74.2, J75.3, U19.GND, U19.GND@1, U19.GND@2
GND19: C39.2, C40.2, J78.1, J78.2, J79.3, U20.GND, U20.GND@1, U20.GND@2
GND20: C41.2, C42.2, J82.1, J82.2, J83.3, U21.GND, U21.GND@1, U21.GND@2
GND21: C43.2, C44.2, J86.1, J86.2, J87.3, U22.GND, U22.GND@1, U22.GND@2
GND22: C45.2, C46.2, J90.1, J90.2, J91.3, U23.GND, U23.GND@1, U23.GND@2
GND23: C47.2, C48.2, J94.1, J94.2, J95.3, U24.GND, U24.GND@1, U24.GND@2
GND24: C49.2, C50.2, J98.1, J98.2, J99.3, U25.GND, U25.GND@1, U25.GND@2
GND25: C51.2, C52.2, J102.1, J102.2, J103.3, U26.GND, U26.GND@1, U26.GND@2
GND26: C53.2, C54.2, J106.1, J106.2, J107.3, U27.GND, U27.GND@1, U27.GND@2
GND27: C55.2, C56.2, J110.1, J110.2, J111.3, U28.GND, U28.GND@1, U28.GND@2
GND28: C57.2, C58.2, J114.1, J114.2, J115.3, U29.GND, U29.GND@1, U29.GND@2
GND29: C59.2, C60.2, J118.1, J118.2, J119.3, U30.GND, U30.GND@1, U30.GND@2
unnamed: J3.6, JP2.2
unnamed: J2.9, JP6.2
unnamed: J2.8, JP7.2
unnamed: J3.5, JP1.2
unnamed: J3.4, JP0.2
unnamed: J3.7, JP3.2
unnamed: J3.8, JP4.2
unnamed: J3.9, JP5.2
unnamed: J6.7, JP11.2
unnamed: J6.8, JP10.2
unnamed: J6.6, JP13.2
unnamed: J6.5, JP12.2
unnamed: J6.4, JP14.2
unnamed: J6.9, JP15.2
unnamed: J8.9, JP9.2
unnamed: J8.8, JP8.2
unnamed: J11.7, JP19.2
unnamed: J11.8, JP18.2
unnamed: J11.6, JP21.2
unnamed: J11.5, JP20.2
unnamed: J11.4, JP22.2
unnamed: J11.9, JP23.2
unnamed: J12.9, JP17.2
unnamed: J12.8, JP16.2
unnamed: J15.7, JP27.2
unnamed: J15.8, JP26.2
unnamed: J15.6, JP29.2
unnamed: J15.5, JP28.2
unnamed: J15.4, JP30.2
unnamed: J15.9, JP31.2
unnamed: J16.9, JP25.2
unnamed: J16.8, JP24.2
unnamed: J19.7, JP35.2
unnamed: J19.8, JP34.2
unnamed: J19.6, JP37.2
unnamed: J19.5, JP36.2
unnamed: J19.4, JP38.2
unnamed: J19.9, JP39.2
unnamed: J20.9, JP33.2
unnamed: J20.8, JP32.2
unnamed: J23.7, JP43.2
unnamed: J23.8, JP42.2
unnamed: J23.6, JP45.2
unnamed: J23.5, JP44.2
unnamed: J23.4, JP46.2
unnamed: J23.9, JP47.2
unnamed: J24.9, JP41.2
unnamed: J24.8, JP40.2
unnamed: J27.7, JP51.2
unnamed: J27.8, JP50.2
unnamed: J27.6, JP53.2
unnamed: J27.5, JP52.2
unnamed: J27.4, JP54.2
unnamed: J27.9, JP55.2
unnamed: J28.9, JP49.2
unnamed: J28.8, JP48.2
unnamed: J31.7, JP59.2
unnamed: J31.8, JP58.2
unnamed: J31.6, JP61.2
unnamed: J31.5, JP60.2
unnamed: J31.4, JP62.2
unnamed: J31.9, JP63.2
unnamed: J32.9, JP57.2
unnamed: J32.8, JP56.2
unnamed: J35.7, JP67.2
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

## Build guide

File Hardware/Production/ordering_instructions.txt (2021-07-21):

panel size, 131x200mm
PCB thickness, 1.6mm
number of layers, 2
soldermask color, Black
silkscreen color, White
oz copper, 1oz
finish, HASL lead free
stencils, none
pcs per panel, 30
min trace width, 0.1778mm / 0.0070in
min drill size, 0.3048mm / 0.0120in

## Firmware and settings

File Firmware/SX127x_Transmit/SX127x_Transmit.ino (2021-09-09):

/*
  RadioLib SX1276 Transmit Example using the RFM97C 915MHz

  Gotchas:
    * The RadioLib defaults the SX1276 to 434MHz so the reception is pretty
      poor. This is fixed with a radio.begin(915.0);
    * The RadioLib really requires DIO0 and DIO1 be connected. Reset is optional.
    * Avoid ESP pins 34/35/36/39 as they are inputs only
*/

#include <RadioLib.h> //Click here to get the library: http://librarymanager/All#RadioLib

// SX1276 has the following connections on the SparkFun ESP32 Thing Plus C:
int pin_cs = 15;
int pin_dio0 = 26; //aka A0
int pin_nrst = 32;
int pin_dio1 = 25; //aka A1
SX1276 radio = new Module(pin_cs, pin_dio0, pin_nrst, pin_dio1);

void setup() {
  Serial.begin(115200);
  delay(500); //Wait for ESP32 to be able to print

  Serial.print(F("[SX1276] Initializing ... "));
  //int state = radio.begin(); //-121dBm
  //int state = radio.begin(868.0); //-20dBm
  int state = radio.begin(915.0); //-23dBm
  if (state == ERR_NONE) {
    Serial.println(F("init success!"));
  } else {
    Serial.print(F("failed, code "));
    Serial.println(state);
    while (true);
  }

  // set output power to 10 dBm (accepted range is -3 - 17 dBm)
  // NOTE: 20 dBm value allows high power operation, but transmission
  //       duty cycle MUST NOT exceed 1%
//  if (radio.setOutputPower(20) == ERR_INVALID_OUTPUT_POWER) {
//    Serial.println(F("Selected output power is invalid for this module!"));
//    while (true);
//  }

  // some modules have an external RF switch
  // controlled via two pins (RX enable, TX enable)
  // to enable automatic control of the switch,
  // call the following method
//  int pin_rx_enable = 4;
//  int pin_tx_enable = 17;
//  radio.setRfSwitchPins(pin_rx_enable, pin_tx_enable);
}

int counter = 0;

void loop() {
  Serial.print(F("[SX1276] Transmitting packet ... "));

  // you can transmit C-string or Arduino string up to
  // 256 characters long
  // NOTE: transmit() is a blocking method!
  //       See example SX127x_Transmit_Interrupt for details
  //       on non-blocking transmission method.

  char output[50];
  sprintf(output, "Counter: %d", counter++);

  int state = radio.transmit(output);

  // you can also transmit byte array up to 256 bytes long
  /*
    byte byteArr[] = {0x01, 0x23, 0x45, 0x67, 0x89, 0xAB, 0xCD, 0xEF};
    int state = radio.transmit(byteArr, 8);
  */

  if (state == ERR_NONE) {
    // the packet was successfully transmitted
    Serial.println(F(" success!"));

    // print measured data rate
    Serial.print(F("[SX1276] Datarate:\t"));
    Serial.print(radio.getDataRate());
    Serial.println(F(" bps"));

  } else if (state == ERR_PACKET_TOO_LONG) {
    // the supplied packet was longer than 256 bytes
    Serial.println(F("too long!"));

  } else if (state == ERR_TX_TIMEOUT) {
    // timeout occurred while transmitting packet
    Serial.println(F("timeout!"));

  } else {
    // some other error occurred
    Serial.print(F("failed, code "));
    Serial.println(state);
  }

  // wait for a second before transmitting again
  delay(1000);
}

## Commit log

2021-07-09 Add datasheet. Organize repo.
    [SparkFun_RFM97CW_Breakout.brd, SparkFun_RFM97CW_Breakout.sch]
2021-07-12 Add x02 hardware files
    [SparkFun_RFM97CW_Breakout_x02.brd, SparkFun_RFM97CW_Breakout_x02.sch]
2021-07-21 Adding panel for x02
    [SparkFun_RFM97CW_Breakout.GBL, SparkFun_RFM97CW_Breakout.GBP, SparkFun_RFM97CW_Breakout.GBS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]
2021-09-09 Add example sketches. Move silk indicator to match dimple on RF shield. Create x03 panels.
    [SparkFun_RFM97CW_Breakout-Panel.GBL, SparkFun_RFM97CW_Breakout-Panel.GBP, SparkFun_RFM97CW_Breakout-Panel.GBS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]

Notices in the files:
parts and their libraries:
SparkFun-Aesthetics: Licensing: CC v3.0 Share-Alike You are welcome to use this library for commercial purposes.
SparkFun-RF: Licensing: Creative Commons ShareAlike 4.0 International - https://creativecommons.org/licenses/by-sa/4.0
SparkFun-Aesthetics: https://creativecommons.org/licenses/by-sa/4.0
